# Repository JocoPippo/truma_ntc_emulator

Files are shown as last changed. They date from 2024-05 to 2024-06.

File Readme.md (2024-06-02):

## TRUMA NTC EMU
Questo progetto è nato per risolvere il problema dell'instabilità della regolazione della stufa truma.
In rete si trovano altri progetti che si basano sulla regolazione di tipo on/off con i sistemi più disparati, 
putroppo questo tipo di regolazioni mal si abbina alla stufa poichè non consente di sfruttare la regolazione della
velocità e della portata del riscaldatore.
Ho cercato di superare questo problema utilizzando un potenziometro digitale abbinato ad un microcontrollore STM32f103.
Nel folder HW è presente lo schema elettrico e il pcb in formato kicad.
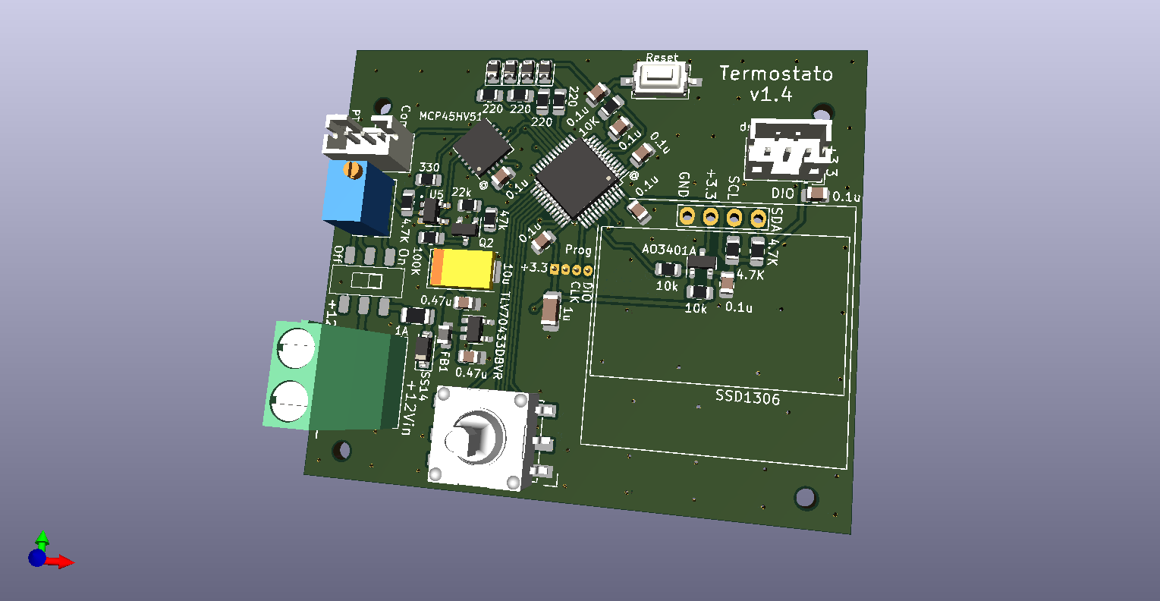
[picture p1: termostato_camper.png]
pcb

Nel folder cubePrj è presente l'export da Stm32CubeIde del progetto. 
Attualmente sono stati sviluppati due portotipi che sono installati per il test.

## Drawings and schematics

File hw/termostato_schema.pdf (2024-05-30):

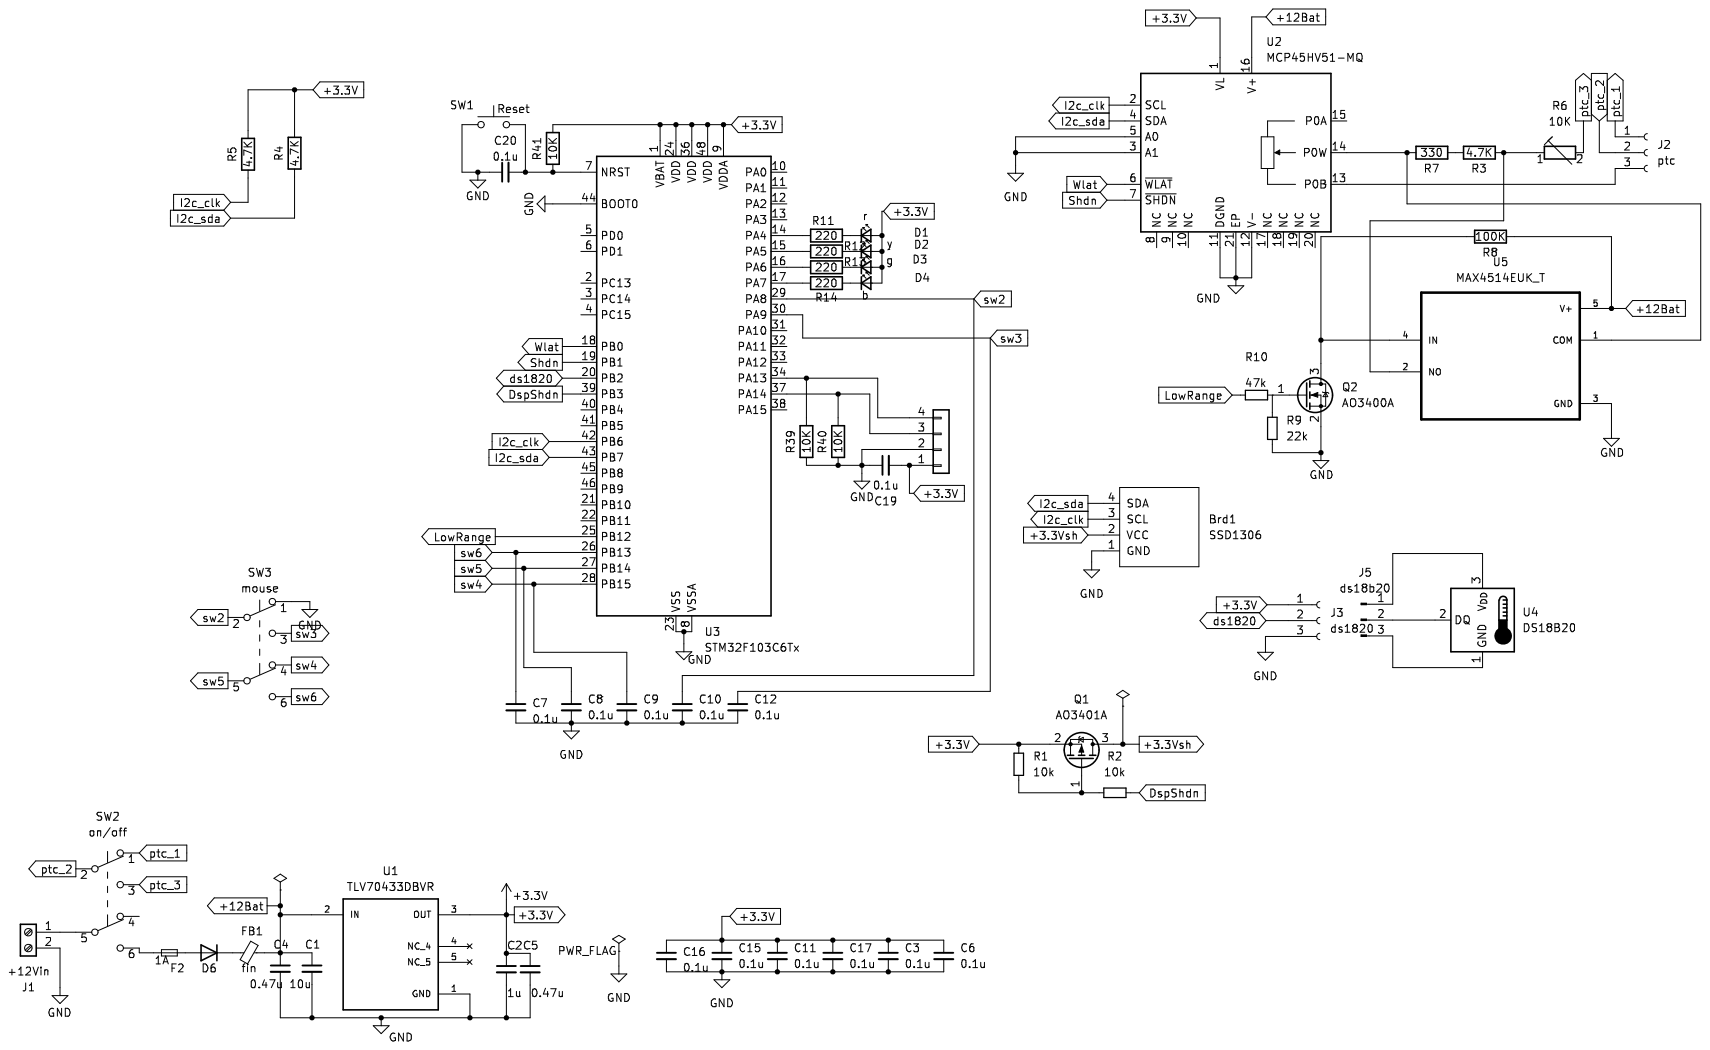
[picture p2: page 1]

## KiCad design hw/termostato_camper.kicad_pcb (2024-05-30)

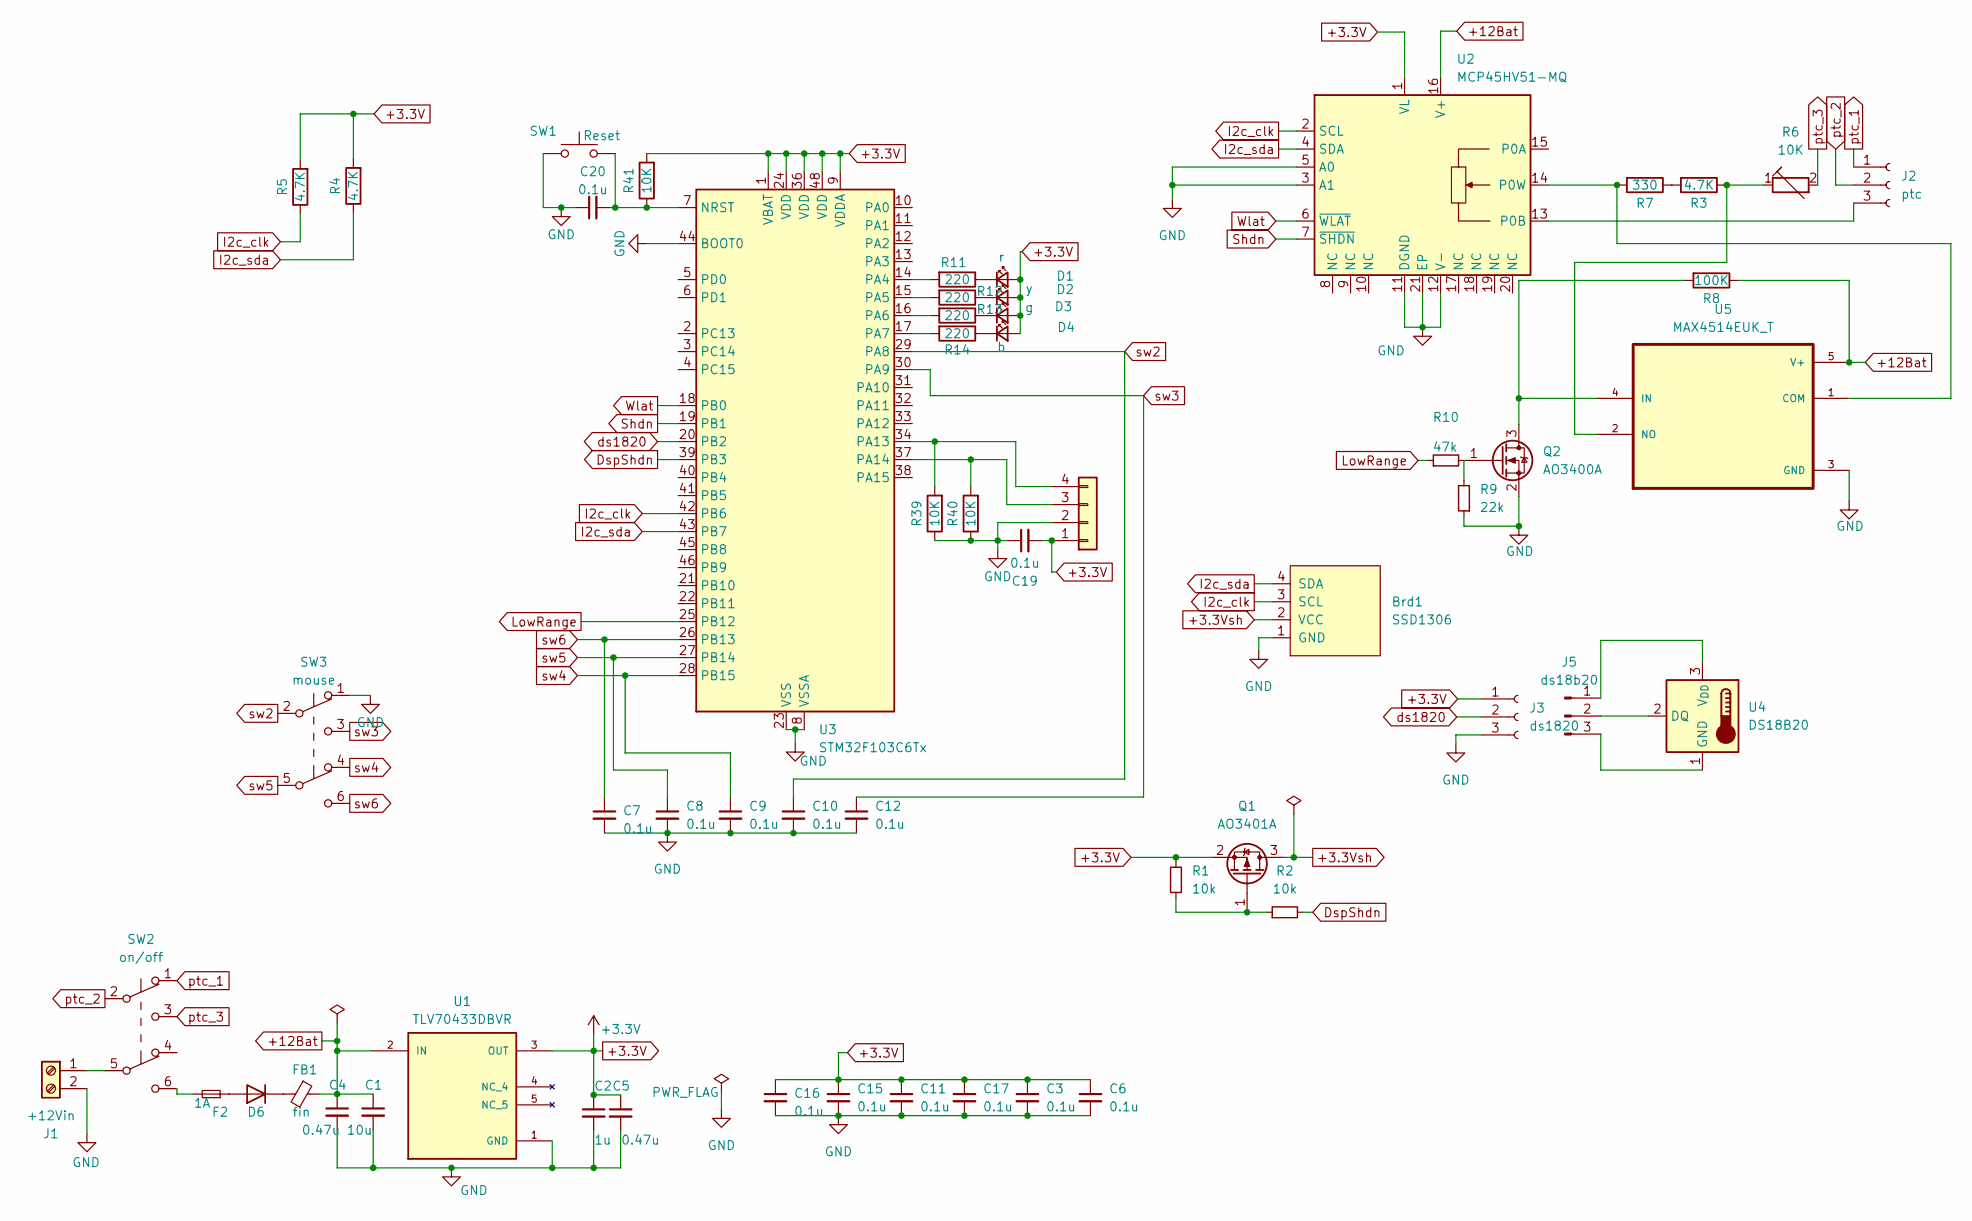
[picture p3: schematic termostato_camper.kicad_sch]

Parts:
Brd1: SSD1306; 128x64OLED
C1: 10u; CP_EIA-7343-15_Kemet-W
C2: 1u; C_1206_3216Metric_Pad1.33x1.80mm_HandSolder
C3, C6, C7, C8, C9, C10, C11, C12, C15, C16, C17, C19, C20: 0.1u; C_0805_2012Metric
C4, C5: 0.47u; C_0805_2012Metric_Pad1.18x1.45mm_HandSolder
D1: r; D_0805_2012Metric
D2: y; D_0805_2012Metric
D3: g; D_0805_2012Metric
D4: b; D_0805_2012Metric
D6: SS14; D_SOD-123
F2: 1A; Fuse_1206_3216Metric
FB1: fin; L_0805_2012Metric
J1: +12Vin; TerminalBlock_Phoenix_MKDS-1,5-2-5.08_1x02_P5.08mm_Horizont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
J2: ptc; JST_XA_B03B-XASK-1_1x03_P2.50mm_Vertical
J3: ds1820; JST_XA_B03B-XASK-1_1x03_P2.50mm_Vertical
J4: Jtag; PinSocket_1x04_P1.27mm_Vertical
J5: ds18b20
Q1: AO3401A; SOT-23
Q2: AO3400A; SOT-23
R1, R2: 10k; R_0805_2012Metric
R3, R4, R5: 4.7K; R_0805_2012Metric_Pad1.20x1.40mm_HandSolder
R6: 10K; Potentiometer_Bourns_3266Y_Vertical
R7: 330; R_0805_2012Metric_Pad1.20x1.40mm_HandSolder
R8: 100K; R_0805_2012Metric_Pad1.20x1.40mm_HandSolder
R9: 22k; R_0805_2012Metric
R10: 47k; R_0805_2012Metric
R11, R12, R13, R14: 220; R_0805_2012Metric_Pad1.20x1.40mm_HandSolder
R39, R40, R41: 10K; R_0805_2012Metric_Pad1.20x1.40mm_HandSolder
SW1: Reset; SW_Tactile_SPST_NO_Straight_CK_PTS636Sx25SMTRLFS
SW2: on/off; switch_dpdt
SW3: mouse; tactile_5
U1: TLV70433DBVR; SOT-23-5; PARTREV D
U2: MCP45HV51-MQ; QFN-20-1EP_5x5mm_P0.65mm_EP3.35x3.35mm
U3: STM32F103C6Tx; LQFP-48_7x7mm_P0.5mm
U4: DS18B20
U5: MAX4514EUK_T; SOT95P280X145-5N

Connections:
+3.3V: C2.1, C3.1, C5.1, C6.1, C11.1, C15.1, C16.1, C17.1, C19.2, D1.2 (A), D2.2 (A), D3.2 (A), D4.2 (A), J3.1, J4.1, Q1.2 (S), R1.2, R4.2, R5.2, R41.2, U1.3 (OUT), U2.1 (VL), U3.1 (VBAT), U3.9 (VDDA), U3.24 (VDD), U3.36 (VDD), U3.48 (VDD)
+3.3Vsh: Brd1.2 (VCC), Q1.3 (D)
+12Bat: C1.1, C4.1, FB1.1, R8.1, U1.2 (IN), U2.16 (V+), U5.5 (V+)
DspShdn: R2.2, U3.39 (PB3)
GND: Brd1.1 (GND), C1.2, C2.2, C3.2, C4.2, C5.2, C6.2, C7.2, C8.2, C9.2, C10.2, C11.2, C12.2, C15.2, C16.2, C17.2, C19.1, C20.1, J1.2, J3.3, J4.2, Q2.2 (S), R9.1, R39.1, R40.1, SW1.1, SW3.1 (A), U1.1 (GND), U1.4 (NC_4), U1.5 (NC_5), U2.3 (A1), U2.5 (A0), U2.11 (DGND), U2.12 (V-), U2.21 (EP), U3.8 (VSSA), U3.23 (VSS), U3.35 (VSS), U3.44 (BOOT0), U3.47 (VSS), U5.3 (GND)
I2c_clk: Brd1.3 (SCL), R5.1, U2.2 (SCL), U3.42 (PB6)
I2c_sda: Brd1.4 (SDA), R4.1, U2.4 (SDA), U3.43 (PB7)
LowRange: R10.1, U3.25 (PB12)
unnamed: D1.1 (K), R11.1
unnamed: D2.1 (K), R12.1
unnamed: D3.1 (K), R13.1
unnamed: D4.1 (K), R14.1
unnamed: D6.2 (A), F2.1
unnamed: D6.1 (K), FB1.2
unnamed: F2.2, SW2.6 (C)
unnamed: J1.1, SW2.5 (B)
unnamed: J2.3, U2.13 (P0B)
unnamed: J4.3, R40.2, U3.37 (PA14)
unnamed: J4.4, R39.2, U3.34 (PA13)
unnamed: J5.1, U4.3 (V_{DD})
unnamed: J5.2, U4.2 (DQ)
unnamed: J5.3, U4.1 (GND)
unnamed: Q1.1 (G), R1.1, R2.1
unnamed: Q2.3 (D), R8.2, U5.4 (IN)
unnamed: Q2.1 (G), R9.2, R10.2
unnamed: R3.2, R7.1
unnamed: R7.2, U2.14 (P0W), U5.1 (COM)
unnamed: C20.2, R41.1, SW1.2, U3.7 (NRST)
unnamed: R11.2, U3.14 (PA4)
unnamed: R12.2, U3.15 (PA5)
unnamed: R13.2, U3.16 (PA6)
unnamed: R14.2, U3.17 (PA7)
unnamed: R3.1, R6.1, U5.2 (NO)
Shdn: U2.7 (~SHDN), U3.19 (PB1)
Wlat: U2.6 (~WLAT), U3.18 (PB0)
ds1820: J3.2, U3.20 (PB2)
ptc_1: J2.1, SW2.1 (A)
ptc_2: J2.2, SW2.2 (B)
ptc_3: R6.2, SW2.3 (C)
sw2: C10.1, SW3.2 (B), U3.29 (PA8)
sw3: C12.1, SW3.3 (C), U3.30 (PA9)
sw4: C9.1, SW3.4 (A), U3.28 (PB15)
sw5: C8.1, SW3.5 (B), U3.27 (PB14)
sw6: C7.1, SW3.6 (C), U3.26 (PB13)

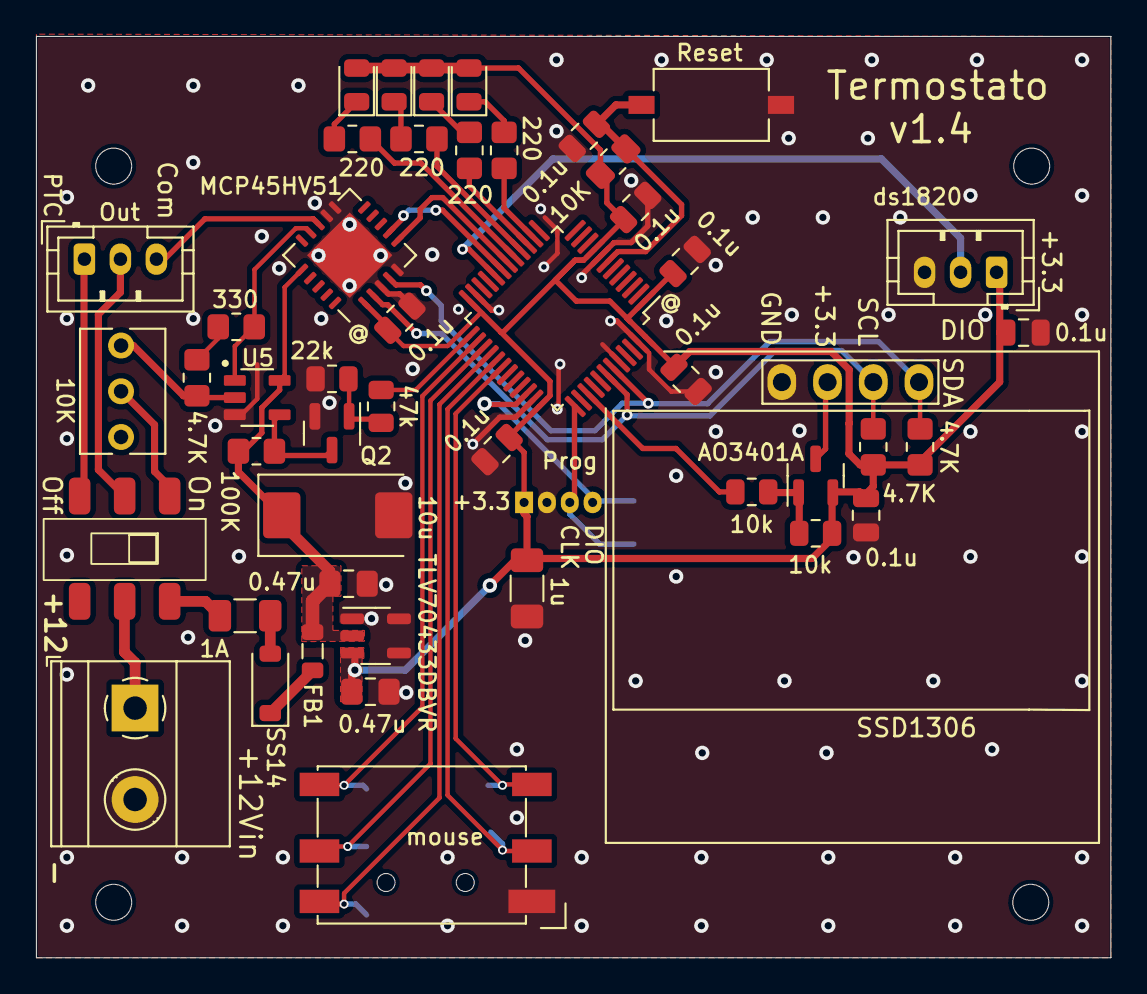
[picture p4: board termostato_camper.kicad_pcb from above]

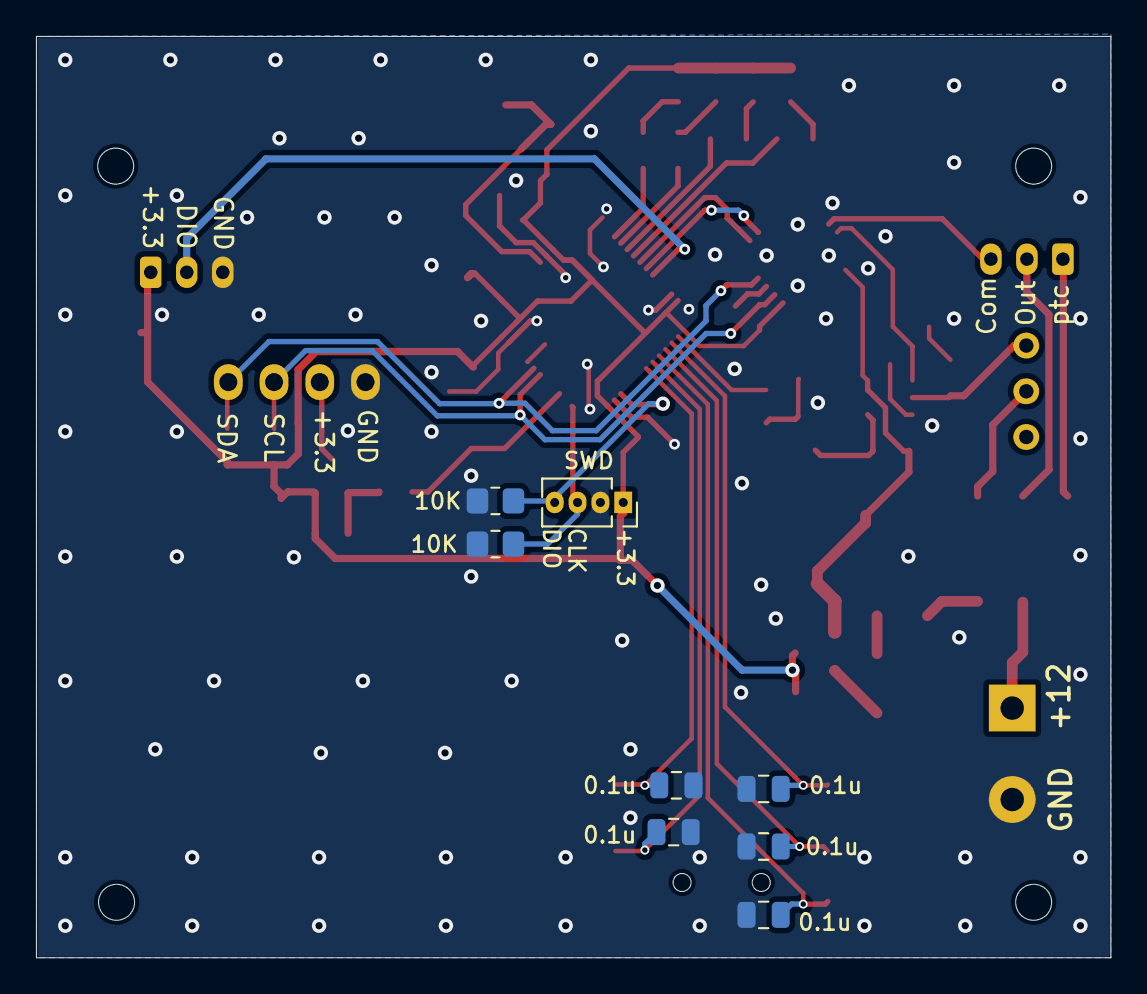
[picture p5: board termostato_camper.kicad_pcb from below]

Board: 2 copper layers, 59.7 x 51.2 mm, 55 parts (8 on the bottom side), 41 nets.

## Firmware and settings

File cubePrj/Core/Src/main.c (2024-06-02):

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
/* Includes ------------------------------------------------------------------*/
#include "main.h"

/* USER CODE BEGIN Includes */
#include <stdio.h>
#include <math.h>
#include "ds18b20.h"
#include "ssd1306.h"
#include "mcp45hv51.h"
#include "eeprom.h"

/* USER CODE END Includes */

/* USER CODE BEGIN PD */

#define MAIN_MENU_IDX 		0
#define ROW_CHANGED(data)	(data & 0x10)
#define ROW_CHANGE_CLEAR  	0xcf
#define ROW_CHANGE_SET		0x10
#define ROW_SETTING_ON		0x20
#define ROW_SELECTED_MASK   0x0f

#define BUTTON_LONG_TIME		5;

#define WIPER_UPPER_STEP 		255
#define WIPER_RES				5000.0
#define WIPER_OHMxSTEP 			(WIPER_RES/WIPER_UPPER_STEP)
#define WIPER_OHM_AT_POS(pos)	((pos*WIPER_RES)/WIPER_UPPER_STEP)

#define BASE_RES 		10000
#define REF_TEMP 		(25+273.25)
#define REF_TEMP_INV	(1/REF_TEMP)

#define SETTING_POS_CHAR 12
#define SETTING_MAX_ROW 4


#define HAS_DIAG 0

/* USER CODE END PD */

I2C_HandleTypeDef hi2c1;

RTC_HandleTypeDef hrtc;

TIM_HandleTypeDef htim1;
TIM_HandleTypeDef htim2;
TIM_HandleTypeDef htim3;

/* USER CODE BEGIN PV */
char display_row[SSD1306_WIDTH / 7 + 1];
unsigned char hasToGoInStop;
//uint8_t setTempH, setTempL;

//eeprom stored data
uint16_t __attribute__ ((section (".noinit"))) beta;
uint16_t __attribute__ ((section (".noinit"))) lowRes_value;
uint16_t __attribute__ ((section (".noinit"))) ohm_correction;
uint16_t __attribute__ ((section (".noinit"))) loopTime;
uint16_t __attribute__ ((section (".noinit"))) tempSet;
uint16_t __attribute__ ((section (".noinit"))) thresh_temp;
uint16_t __attribute__ ((section (".noinit"))) deltaT;
uint16_t __attribute__ ((section (".noinit"))) deltaR;

uint16_t loopCycles;

//         T * T0      Rt
// Beta = -------- ln ----
//         T0 - T      R0

//                           1     1
// Rt = R0 * exp ( Beta * ( --- - --- )
//                           T     T0

//             Beta
// T = ---------------------
//          Rt     Beta
//      ln ---- + ------
//          R0*     T0

//uint16_t beta;  // T1 = 25 + 273.15

// menu related
typedef void (*menuMethodPtr)(void);
typedef struct menuItem {
	uint8_t ref;
	uint8_t prev;
	uint8_t next;
	char *title;
	menuMethodPtr fptr;
	uint8_t tout;
} menuItem_t;

#if defined HAS_DIAG && HAS_DIAG == 1
menuItem_t menu[] = { { MAIN_MENU_IDX, MAIN_MENU_IDX, 1, "Main", mainmenu, 30 }, { 1, MAIN_MENU_IDX, 2, "Diagnostica", diagnostic, 30 }, { 2, 1, 3,
		"T. Settings", settingsTemp, 30 }, { 3, 2, 3, "Gen Settings", settingsGlob, 30 } };
#else
menuItem_t menu[] = { { MAIN_MENU_IDX, MAIN_MENU_IDX, 1, "Main", mainmenu, 30 }, { 1, MAIN_MENU_IDX, 2,
		"T. Settings", settingsTemp, 30 }, { 2, 1, 2, "Gen Settings", settingsGlob, 30 } };
#endif


uint8_t buttonTime = 0;
uint8_t currentMenu = 0;
uint8_t display2Update = 1;
uint8_t selectedRow = 1;
uint8_t mode;
uint8_t displayTime2Wait = 30;
// button related
// must be thread safe
uint16_t buttons_state = 0;
//uint8_t settings_mode = 0;

/* USER CODE END PV */

void SystemClock_Config(void);
static void MX_GPIO_Init(void);
static void MX_I2C1_Init(void);
static void MX_TIM3_Init(void);
static void MX_TIM1_Init(void);
static void MX_RTC_Init(void);
static void MX_TIM2_Init(void);
/**
  * @brief  The application entry point.
  * @retval int
  */
int main(void)
{

  /* MCU Configuration--------------------------------------------------------*/

  /* Reset of all peripherals, Initializes the Flash interface and the Systick. */
  HAL_Init();

  /* Configure the system clock */
  SystemClock_Config();

  /* Initialize all configured peripherals */
  MX_GPIO_Init();
  MX_I2C1_Init();
  MX_TIM3_Init();
  MX_TIM1_Init();
  MX_RTC_Init();
  MX_TIM2_Init();
  /* Infinite loop */
  /* USER CODE BEGIN WHILE */
	eepromInit();
	loadDataFromEEprom();
	// for Temperature Acquisition
	HAL_TIM_Base_Start(&htim3);
	HAL_TIM_Base_Start_IT(&htim1);
	HAL_TIM_Base_Start_IT(&htim2);
	//HAL_TIMEx_OCN_Start_IT(&htim1, TIM_CHANNEL_1);

	// take return value ...
	mcp45hv51_Init();

	SSD1306_Init();
	SSD1306_GotoXY(0, 0);
	SSD1306_Puts("      TRUMA", &Font_7x10, 1);
	SSD1306_GotoXY(0, 12);
	SSD1306_Puts("  Emulatore NTC", &Font_7x10, 1);
	SSD1306_GotoXY(0, 24);
//	sprintf(display_row, "WIPER POS: %u", readWiper());

	SSD1306_Puts(display_row, &Font_7x10, 1);
	SSD1306_UpdateScreen();
	HAL_Delay(1000);
	display2Update = 1;
	currentMenu = 0;
	hasToGoInStop = 0;
	uint8_t oldGoInStop = hasToGoInStop;
	while (1) {
		if(oldGoInStop == 1 && oldGoInStop != hasToGoInStop) {
//			//waked-up by external interrupt restore
			SSD1306_ON();
			SSD1306_Init();
			oldGoInStop = hasToGoInStop;
		}
		//check if timeout reached
		if(displayTime2Wait==0) {
			//discard every parameter changes
			selectedRow &= ~ROW_SETTING_ON;
			selectedRow |= ROW_CHANGE_SET;
			loadDataFromEEprom();
			//if already on main menu then shutdown the display and enable the hasToGoInStop
			if(currentMenu == MAIN_MENU_IDX) {
				hasToGoInStop = 1;
				oldGoInStop = hasToGoInStop;
				SSD1306_OFF();
			}
			else {
				//return to the main menu
				currentMenu = MAIN_MENU_IDX;
				//reload the timer for the main menu
				displayTime2Wait= menu[currentMenu].tout;
				display2Update = 1;
			}
		}
		if (display2Update != 0) {
			updateMenu();
		}

		if (hasToGoInStop == 0) {
			menu[currentMenu].fptr();
			SSD1306_UpdateScreen();
		}
		settingOperation();
    /* USER CODE END WHILE */

    /* USER CODE BEGIN 3 */
		//HAL_Delay(200); //system wait

		if (hasToGoInStop == 1) {
			//set a mock time
			RTC_TimeTypeDef time = { 10U, 11U, 10U };
			HAL_RTC_SetTime(&hrtc, &time, RTC_FORMAT_BIN);

			// set alarm time for 20 RTC cycle about 20 sec
			RTC_AlarmTypeDef alarm = { { 10U, 11U, 30U }, RTC_ALARM_A };
			HAL_RTC_SetAlarm_IT(&hrtc, &alarm, RTC_FORMAT_BIN);

			/*Suspend Tick increment to prevent wakeup by Systick interrupt.
			 Otherwise the Systick interrupt will wake up the device within 1ms (HAL time base)*/
			HAL_SuspendTick();
			//stop timer 1 to avoid interrupt
			HAL_TIM_Base_Stop_IT(&htim1);
			//stop timer 2 to avoid interrupt
			HAL_TIM_Base_Stop_IT(&htim2);
			//go in stop mode. it we waked up from alarm every 20s
			__HAL_PWR_CLEAR_FLAG(PWR_FLAG_WU);
			//Go in stop mode
			//HAL_PWR_EnterSTOPMode(PWR_MAINREGULATOR_ON, PWR_STOPENTRY_WFI);
			HAL_PWR_EnterSTOPMode(PWR_LOWPOWERREGULATOR_ON, PWR_STOPENTRY_WFI);
			//waked up from RTC or by pressing a button
			//restore other form of interrupt
			HAL_ResumeTick();
			//restart timers
			HAL_TIM_Base_Start_IT(&htim1);
			HAL_TIM_Base_Start_IT(&htim2);

		} // end if hasToCoInStop

	}
  /* USER CODE END 3 */
}

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
/* USER CODE BEGIN 4 */


uint8_t getWiperRFromTemp(uint8_t taH, uint8_t taL, uint16_t *resT, uint16_t *res) {
	uint8_t wiper = 0xff;
	float resistance = 10000;
	float currentTemp = 273.25;

	int16_t temp = evalTempEquival(taH, taL);
	// check if T is in the linearization zone
	int16_t dT = temp - thresh_temp;
	if (dT > (-deltaT) && dT < deltaT) {
		// in this case we apply a new and specific rule base on hysteresisR/hysteresisT
		currentTemp += (thresh_temp / 10.0);
		float resistanceBase = BASE_RES * exp(-beta * (REF_TEMP_INV - 1 / currentTemp));
		// now apply a linear constrain based on provide data
		int16_t dR = -(dT * deltaR) / deltaT; // LPP check the sign this behavior must be like an NTC
		resistance = resistanceBase + dR;
	} else {
		currentTemp += (temp / 10.0);
		resistance = BASE_RES * exp(-beta * (REF_TEMP_INV - 1 / currentTemp));
	}
	*resT=(uint16_t)resistance;
	resistance -= ohm_correction;

	if (resistance > WIPER_RES) {
		setLowRange(1);
		resistance -= lowRes_value;
	} else {
		setLowRange(0);
	}
	*res=(uint16_t)resistance;
	wiper=255;
	if (resistance <= WIPER_RES) {
		wiper = (resistance / WIPER_OHMxSTEP);
	}
	return wiper;
}


void mainmenu() {
	//{0,0,1,"Main", mainmenu, 30}
	// on first available row -> below title 7x10
	uint8_t Temp_byte; //, Temp_byte2;
	uint16_t TEMP;
	uint8_t yPos = Font_7x10.FontHeight + 1;
	//Temperature Acquisition
	DS18B20_Start();
	HAL_Delay(1);
	DS18B20_Write(0xCC);  // skip ROM
	DS18B20_Write(0x44);  // convert t
	HAL_Delay(3);
	DS18B20_Start();
	HAL_Delay(1);
	DS18B20_Write(0xCC);  // skip ROM
	DS18B20_Write(0xBE);  // Read Scratch-pad
	Temp_byte = DS18B20_Read();
	TEMP = (DS18B20_Read() << 8) | Temp_byte;
	SSD1306_GotoXY(0, yPos);
	uint8_t tempH = (TEMP / 16);
	uint8_t tempL = (TEMP * 10 / 16 - tempH * 10);
	sprintf(display_row, "Amb Temp: %2u.%1u", tempH, tempL);
	//SSD1306_Puts(display_row, &Font_11x18, 1);
	SSD1306_Puts(display_row, &Font_7x10, 1);
	// on second row -> below temp 11x18
	//yPos += Font_11x18.FontHeight+1;
	yPos += Font_7x10.FontHeight + 1;
	SSD1306_GotoXY(0, yPos);
	uint8_t setTempH = (tempSet / 10);
	uint8_t setTempL = tempSet - (setTempH * 10);

	sprintf(display_row, "Set Temp: %2u.%1u", setTempH, setTempL);
	SSD1306_Puts(display_row, &Font_7x10, 1);

	//uint8_t newWiper = getWiperFromTemp(tempH, tempL);
	uint16_t resTArg, res;
	uint8_t newWiper = getWiperRFromTemp(tempH, tempL, &resTArg, &res);
	writeWiper(newWiper);

	///// TO REMOVE ////////////////////////
	yPos += Font_7x10.FontHeight + 1;
	SSD1306_GotoXY(0, yPos);
	sprintf(display_row, "Rt=%5u;R:%5u", resTArg, res);
	SSD1306_Puts(display_row, &Font_7x10, 1);

	uint8_t wiper = readWiper();
	yPos += Font_7x10.FontHeight + 1;
	SSD1306_GotoXY(0, yPos);
//	sprintf(display_row, "Wiper: %3u", wiper);
	sprintf(display_row, "Wiper: %3u", wiper);
	SSD1306_Puts(display_row, &Font_7x10, 1);
	////////////////////////////////////////

	SSD1306_UpdateScreen(); // added also here to avoid delay

//	loopCycles = (loopTime * 5) - 1; //hyp small loop are 200ms
//	while (loopCycles > 0) {
//		HAL_Delay(200);
//		loopCycles--;
//	}

}

void settingOperation() {
	uint8_t Temp_byte; //, Temp_byte2;
	uint16_t TEMP;
	//Temperature Acquisition
	DS18B20_Start();
	HAL_Delay(1);
	DS18B20_Write(0xCC);  // skip ROM
	DS18B20_Write(0x44);  // convert t
	HAL_Delay(3);
	DS18B20_Start();
	HAL_Delay(1);
	DS18B20_Write(0xCC);  // skip ROM
	DS18B20_Write(0xBE);  // Read Scratch-pad
	Temp_byte = DS18B20_Read();
	TEMP = (DS18B20_Read() << 8) | Temp_byte;
	uint8_t tempH = (TEMP / 16);
	uint8_t tempL = (TEMP * 10 / 16 - tempH * 10);

	uint16_t r1, r2;
	uint8_t newWiper = getWiperRFromTemp(tempH, tempL, &r1, &r2);
	writeWiper(newWiper);

	loopCycles = (loopTime * 5) - 1; //hyp small loop are 200ms
	while (loopCycles > 0) {
		HAL_Delay(200);
		loopCycles--;
	}

}

void diagnostic() {
#if defined HAS_DIAG && HAS_DIAG == 1
	//{1,0,2,"Diagnostica", diagnostic, 30},
	// on first available row -> below title 7x10
	uint8_t yPos = Font_7x10.FontHeight + 1;
	uint8_t wiper = readWiper();

	int ntcValue = evalResistance(wiper);
	uint8_t equTempH;
	uint8_t equTempL;
	evalTemp(ntcValue, &equTempH, &equTempL);

	SSD1306_GotoXY(0, yPos);
	sprintf(display_row, "wiper set: %3u", wiper);
	SSD1306_Puts(display_row, &Font_7x10, 1);
	yPos += Font_7x10.FontHeight + 1;
	SSD1306_GotoXY(0, yPos);
	sprintf(display_row, "r %5d, t %2u.%1u", ntcValue, equTempH, equTempL);
	SSD1306_Puts(display_row, &Font_7x10, 1);

	uint8_t Temp_byte; //, Temp_byte2;
	uint16_t TEMP;

	//Temperature Acquisition
	DS18B20_Start();
	HAL_Delay(1);
	DS18B20_Write(0xCC);  // skip ROM
	DS18B20_Write(0x44);  // convert t
	HAL_Delay(3);
	DS18B20_Start();
	HAL_Delay(1);
	DS18B20_Write(0xCC);  // skip ROM
	DS18B20_Write(0xBE);  // Read Scratch-pad
	Temp_byte = DS18B20_Read();
	TEMP = (DS18B20_Read() << 8) | Temp_byte;
	uint8_t tempH = (TEMP / 16);
	uint8_t tempL = (TEMP * 10 / 16 - tempH * 10);

	yPos += Font_7x10.FontHeight + 1;
	SSD1306_GotoXY(0, yPos);
	wiper = getWiperFromTemp(tempH, tempL);
	ntcValue = evalResistance(wiper);
	sprintf(display_row, "Tamb: %2u.%1u", tempH, tempL);
	SSD1306_Puts(display_row, &Font_7x10, 1);
	yPos += Font_7x10.FontHeight + 1;
	SSD1306_GotoXY(0, yPos);
	sprintf(display_row, "wip:%3u res:%5u", wiper, ntcValue);
	SSD1306_Puts(display_row, &Font_7x10, 1);
#endif
}

void settingsGlob() {
	//{3,2,3,"Impostazioni", settings, 30}
	if ((selectedRow & ROW_SETTING_ON) != 0) {
		uint8_t xPos = SETTING_POS_CHAR * Font_7x10.FontWidth;
		uint8_t yPos = (selectedRow & ROW_SELECTED_MASK) * (Font_7x10.FontHeight + 2) - 1;
		SSD1306_DrawFilledRectangle(0, yPos, xPos, Font_7x10.FontHeight, SSD1306_COLOR_WHITE);
		SSD1306_DrawFilledRectangle(xPos, yPos, SSD1306_WIDTH, Font_7x10.FontHeight, SSD1306_COLOR_BLACK);
		SSD1306_GotoXY(0, yPos);
		if ((buttons_state & SU_BTN) != 0) {
			//increment value
			switch ((selectedRow & ROW_SELECTED_MASK)) {
			case 1:
				lowRes_value += 10;
				if (lowRes_value > 6000)
					lowRes_value = 6000;
				break;
			case 2:
				ohm_correction += 10;
				if (ohm_correction > 10000)
					ohm_correction = 10000;
				break;
			case 3:
				beta += 100;
				if (beta > 10000)
					beta = 10000;
				break;
			case 4:
				loopTime += 1;
				if (beta > 180)
					beta = 180;
				break;
			default:
				break;
			}
		}
		//enter in setting mode
		if ((buttons_state & GIU_BTN) != 0) {
			//decrement value
			switch ((selectedRow & ROW_SELECTED_MASK)) {
			case 1:
				lowRes_value -= 10;
				if (lowRes_value < 4000)
					lowRes_value = 4000;
				break;
			case 2:
				ohm_correction -= 10;
				if (ohm_correction < 100)
					ohm_correction = 100;

				break;
			case 3:
				beta -= 100;
				if (beta < 3000)
					beta = 3000;
				break;
			case 4:
				loopTime -= 1;
				if (beta < 1)
					beta = 1;
				break;
			default:
				break;
			}
		}

		switch ((selectedRow & ROW_SELECTED_MASK)) {
		case 1:
			sprintf(display_row, "Low Resis. :%5u", lowRes_value);
			break;
		case 2:
			sprintf(display_row, "Resistance :%5u", ohm_correction);
			break;
		case 3:
			sprintf(display_row, "Beta       :%5u", beta);
			break;
		case 4:
			sprintf(display_row, "Loop Time  :%5u", loopTime);
			break;

		default:
			break;
		}
		SSD1306_Puts_r(display_row, &Font_7x10, SETTING_POS_CHAR, SSD1306_COLOR_WHITE);
	}

	if (ROW_CHANGED(selectedRow) == 0)
		return;
	selectedRow &= ROW_CHANGE_CLEAR;
	uint8_t yPos = Font_7x10.FontHeight + 2;
	uint8_t color = SSD1306_COLOR_WHITE;
	uint8_t row = 1;
	SSD1306_DrawFilledRectangle(0, yPos - 1, SSD1306_WIDTH, SSD1306_HEIGHT - yPos, SSD1306_COLOR_BLACK);

	if (selectedRow == row) {
		color = SSD1306_COLOR_BLACK;
		SSD1306_DrawFilledRectangle(0, yPos - 1, SSD1306_WIDTH, Font_7x10.FontHeight, SSD1306_COLOR_WHITE);
	}
	SSD1306_GotoXY(0, yPos);
	sprintf(display_row, "Low Resis. :%5u", lowRes_value);
	SSD1306_Puts(display_row, &Font_7x10, color);

	row++;
	color = SSD1306_COLOR_WHITE;
	yPos += Font_7x10.FontHeight + 2;
	if (selectedRow == row) {
		color = SSD1306_COLOR_BLACK;
		SSD1306_DrawFilledRectangle(0, yPos - 1, SSD1306_WIDTH, Font_7x10.FontHeight, SSD1306_COLOR_WHITE);
	}
	SSD1306_GotoXY(0, yPos);
	sprintf(display_row, "Resistenza :%5u", ohm_correction);
	SSD1306_Puts(display_row, &Font_7x10, color);

	row++;
	color = SSD1306_COLOR_WHITE;
	yPos += Font_7x10.FontHeight + 2;
	if (selectedRow == row) {
		color = SSD1306_COLOR_BLACK;
		SSD1306_DrawFilledRectangle(0, yPos - 1, SSD1306_WIDTH, Font_7x10.FontHeight, SSD1306_COLOR_WHITE);
	}
	SSD1306_GotoXY(0, yPos);
	sprintf(display_row, "Beta       :%5u", beta);
	SSD1306_Puts(display_row, &Font_7x10, color);

	row++;
	color = SSD1306_COLOR_WHITE;
	yPos += Font_7x10.FontHeight + 2;
	if (selectedRow == row) {
		color = SSD1306_COLOR_BLACK;
		SSD1306_DrawFilledRectangle(0, yPos - 1, SSD1306_WIDTH, Font_7x10.FontHeight, SSD1306_COLOR_WHITE);
	}
	SSD1306_GotoXY(0, yPos);
	sprintf(display_row, "Loop Time  :%5u", loopTime);
	SSD1306_Puts(display_row, &Font_7x10, color);
}

void settingsTemp() {
	//{2,1,3,"Impostazioni", settings, 30}

	if ((selectedRow & ROW_SETTING_ON) != 0) {
		uint8_t xPos = SETTING_POS_CHAR * Font_7x10.FontWidth;
		uint8_t yPos = (selectedRow & ROW_SELECTED_MASK) * (Font_7x10.FontHeight + 2) - 1;
		SSD1306_DrawFilledRectangle(0, yPos, xPos, Font_7x10.FontHeight, SSD1306_COLOR_WHITE);
		SSD1306_DrawFilledRectangle(xPos, yPos, SSD1306_WIDTH, Font_7x10.FontHeight, SSD1306_COLOR_BLACK);
		SSD1306_GotoXY(0, yPos);
		if ((buttons_state & SU_BTN) != 0) {
			//increment value
			switch ((selectedRow & ROW_SELECTED_MASK)) {
			case 1:
				tempSet++;
				if (tempSet > 300)
					tempSet = 300;

				break;
			case 2:
				thresh_temp++;
				if (thresh_temp > 300)
					thresh_temp = 300;
				break;
			case 3:
				deltaT++;
				if (deltaT > 500)
					deltaT = 500;
				break;
			case 4:
				deltaR += 10;
				if (deltaR > 1000)
					deltaR = 1000;
				break;
			default:
				break;
			}
		}
		//enter in setting mode
		if ((buttons_state & GIU_BTN) != 0) {
			//decrement value
			switch ((selectedRow & ROW_SELECTED_MASK)) {
			case 1:
				tempSet--;
				if (tempSet < 100)
					tempSet = 100;
				break;
			case 2:
				thresh_temp--;
				if (thresh_temp < 100)
					thresh_temp = 100;
				break;
			case 3:
				deltaT--;
				if (deltaT < 5)
					deltaT = 5;
				break;
			case 4:
				deltaR -= 10;
				if (deltaR < 20) // minimal step for potentiometer
					deltaR = 20;
				break;
			default:
				break;
			}
		}
		uint8_t thrTempH = (thresh_temp / 10);
		uint8_t thrTempL = thresh_temp - (thrTempH * 10);
		uint8_t setTempH = (tempSet / 10);
		uint8_t setTempL = tempSet - (setTempH * 10);
		switch ((selectedRow & ROW_SELECTED_MASK)) {
		case 1:
			sprintf(display_row, "T setpoint :%3u.%1u", setTempH, setTempL);
			break;
		case 2:
			sprintf(display_row, "TrumaThr T :%3u.%1u", thrTempH, thrTempL);
			break;
		case 3:
			sprintf(display_row, "Delta Temp :%5u", deltaT);
			break;
		case 4:
			sprintf(display_row, "Delta Res. :%5u", deltaR);
			break;
		default:
			break;
		}

		SSD1306_Puts_r(display_row, &Font_7x10, SETTING_POS_CHAR, SSD1306_COLOR_WHITE);
		thresh_temp = (thrTempH * 10) + thrTempL;
	}

	if (ROW_CHANGED(selectedRow) == 0)
		return;
	selectedRow &= ROW_CHANGE_CLEAR;
	uint8_t yPos = Font_7x10.FontHeight + 2;
	uint8_t color = SSD1306_COLOR_WHITE;
	uint8_t row = 1;
	uint8_t thrTempH = (thresh_temp / 10);
	uint8_t thrTempL = thresh_temp - (thrTempH * 10);
	uint8_t setTempH = (tempSet / 10);
	uint8_t setTempL = tempSet - (setTempH * 10);
	;

	SSD1306_DrawFilledRectangle(0, yPos - 1, SSD1306_WIDTH, SSD1306_HEIGHT - yPos, SSD1306_COLOR_BLACK);
	if (selectedRow == row) {
		color = SSD1306_COLOR_BLACK;
		SSD1306_DrawFilledRectangle(0, yPos - 1, SSD1306_WIDTH, Font_7x10.FontHeight, SSD1306_COLOR_WHITE);
	}
	SSD1306_GotoXY(0, yPos);
	sprintf(display_row, "T setpoint :%3u.%1u", setTempH, setTempL);
	SSD1306_Puts(display_row, &Font_7x10, color);

	row++;
	color = SSD1306_COLOR_WHITE;
	yPos += Font_7x10.FontHeight + 2;
	if (selectedRow == row) {
		color = SSD1306_COLOR_BLACK;
		SSD1306_DrawFilledRectangle(0, yPos - 1, SSD1306_WIDTH, Font_7x10.FontHeight, SSD1306_COLOR_WHITE);
	}
	SSD1306_GotoXY(0, yPos);
	sprintf(display_row, "TrumaThr T :%3u.%1u", thrTempH, thrTempL);
	SSD1306_Puts(display_row, &Font_7x10, color);

	row++;
	color = SSD1306_COLOR_WHITE;
	yPos += Font_7x10.FontHeight + 2;
	if (selectedRow == row) {
		color = SSD1306_COLOR_BLACK;
		SSD1306_DrawFilledRectangle(0, yPos - 1, SSD1306_WIDTH, Font_7x10.FontHeight, SSD1306_COLOR_WHITE);
	}
	SSD1306_GotoXY(0, yPos);
	sprintf(display_row, "Delta Temp :%5u", deltaT);
	SSD1306_Puts(display_row, &Font_7x10, color);

	row++;
	color = SSD1306_COLOR_WHITE;
	yPos += Font_7x10.FontHeight + 2;
	if (selectedRow == row) {
		color = SSD1306_COLOR_BLACK;
		SSD1306_DrawFilledRectangle(0, yPos - 1, SSD1306_WIDTH, Font_7x10.FontHeight, SSD1306_COLOR_WHITE);
	}
	SSD1306_GotoXY(0, yPos);
	sprintf(display_row, "Delta Res. :%5u", deltaR);
	SSD1306_Puts(display_row, &Font_7x10, color);

}

void handleMenu(uint8_t sxPress) {
	if (sxPress) {
		// go back if possible
		if (menu[currentMenu].prev != currentMenu) {
			currentMenu = menu[currentMenu].prev;
			display2Update = 1; // for faster irq
			selectedRow = 1 | ROW_CHANGE_SET;
		}
	} else {
		// go next if possible
		if (menu[currentMenu].next != currentMenu) {
			currentMenu = menu[currentMenu].next;
			display2Update = 1; // for faster irq
			selectedRow = 1 | ROW_CHANGE_SET;
		}
	}
	if (menu[currentMenu].fptr != mainmenu) {
		loopCycles = 1;
	}
}

void updateMenu() {
	uint8_t nchar = strlen(menu[currentMenu].title);
	SSD1306_Clear();
	uint8_t xPos = (SSD1306_WIDTH - nchar * Font_7x10.FontWidth) / 2;
	SSD1306_GotoXY(xPos, 0);
	SSD1306_Puts(menu[currentMenu].title, &Font_7x10, 1);
	if (menu[currentMenu].prev != currentMenu) {
		SSD1306_GotoXY(0, 0);
		SSD1306_Putc('<', &Font_7x10, 1);
	}
	if (menu[currentMenu].next != currentMenu) {
		SSD1306_GotoXY(SSD1306_WIDTH - Font_7x10.FontWidth - 1, 0);
		SSD1306_Putc('>', &Font_7x10, 1);
	}
	display2Update = 0;
	displayTime2Wait=menu[currentMenu].tout;
}

void loadDataFromEEprom() {

	lowRes_value = 5000;
	ohm_correction = 7500;
	beta = 3900;
	loopTime = 1; // tempo in secondi
	tempSet = 210;

	thresh_temp = 210;
	deltaT = 5; // in decimi di grado
	deltaR = 240; // estratta da variazione curva con Delta di 1 grado a 23gradi

	eepromLoadParam(RC_KEY1, &beta);
	eepromLoadParam(RC_KEY2, &lowRes_value);
	eepromLoadParam(RC_KEY3, &ohm_correction);
	eepromLoadParam(RC_KEY4, &loopTime);

	eepromLoadParam(RC_KEY5, &tempSet);
	eepromLoadParam(RC_KEY6, &thresh_temp);
	eepromLoadParam(RC_KEY7, &deltaT);
	eepromLoadParam(RC_KEY8, &deltaR);

}

void writeDataOnEEprom() {
#ifdef DEBUG
	return;
#endif

	eepromSaveParam(RC_KEY1, &beta, sizeof(beta));
	eepromSaveParam(RC_KEY2, &lowRes_value, sizeof(lowRes_value));
	eepromSaveParam(RC_KEY3, &ohm_correction, sizeof(ohm_correction));
	eepromSaveParam(RC_KEY4, &loopTime, sizeof(loopTime));
	eepromSaveParam(RC_KEY5, &tempSet, sizeof(tempSet));
	eepromSaveParam(RC_KEY6, &thresh_temp, sizeof(thresh_temp));
	eepromSaveParam(RC_KEY7, &deltaT, sizeof(deltaT));
	eepromSaveParam(RC_KEY8, &deltaR, sizeof(deltaR));
}
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

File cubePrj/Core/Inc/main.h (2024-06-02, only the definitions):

#define mcp_addr 0x3c
#define HundredMsTimer1 99
#define DL_RED_Pin GPIO_PIN_4
#define DL_RED_GPIO_Port GPIOA
#define DL_YELLOW_Pin GPIO_PIN_5
#define DL_YELLOW_GPIO_Port GPIOA
#define DL_GREEN_Pin GPIO_PIN_6
#define DL_GREEN_GPIO_Port GPIOA
#define DL_BLUE_Pin GPIO_PIN_7
#define DL_BLUE_GPIO_Port GPIOA
#define Wlat_Pin GPIO_PIN_0
#define Wlat_GPIO_Port GPIOB
#define Shdn_Pin GPIO_PIN_1
#define Shdn_GPIO_Port GPIOB
#define DS1820_IO_Pin GPIO_PIN_2
#define DS1820_IO_GPIO_Port GPIOB
#define LowRange_Pin GPIO_PIN_12
#define LowRange_GPIO_Port GPIOB
#define SW_SU_Pin GPIO_PIN_13
#define SW_SU_GPIO_Port GPIOB
#define SW_SU_EXTI_IRQn EXTI15_10_IRQn
#define SW_SX_Pin GPIO_PIN_14
#define SW_SX_GPIO_Port GPIOB
#define SW_SX_EXTI_IRQn EXTI15_10_IRQn
#define SW_GIU_Pin GPIO_PIN_15
#define SW_GIU_GPIO_Port GPIOB
#define SW_GIU_EXTI_IRQn EXTI15_10_IRQn
#define SW_DX_Pin GPIO_PIN_8
#define SW_DX_GPIO_Port GPIOA
#define SW_DX_EXTI_IRQn EXTI9_5_IRQn
#define SW_ENTER_Pin GPIO_PIN_9
#define SW_ENTER_GPIO_Port GPIOA
#define SW_ENTER_EXTI_IRQn EXTI9_5_IRQn
#define LCD_Shdn_Pin GPIO_PIN_3
#define LCD_Shdn_GPIO_Port GPIOB
#define RC_KEY1		0
#define RC_KEY2		1
#define RC_KEY3		2
#define RC_KEY4		3
#define RC_KEY5		4
#define RC_KEY6		5
#define RC_KEY7		6
#define RC_KEY8		7
#define ENTER_BTN 0x0001
#define DX_BTN    0x0002
#define GIU_BTN   0x0004
#define SX_BTN    0x0008
#define SU_BTN    0x0010
#define BTN_MASK (0x01<< 5)-1 //n buttons
#define BTN_LONG_MASK 0x0020

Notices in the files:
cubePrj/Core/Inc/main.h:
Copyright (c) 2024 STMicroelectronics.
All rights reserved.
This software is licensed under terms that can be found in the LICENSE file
